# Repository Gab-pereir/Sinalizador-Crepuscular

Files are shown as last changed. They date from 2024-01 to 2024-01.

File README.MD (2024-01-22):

# Sinalizador Crepuscular Automatizado

Seja bem vindo a esse repositório dedicado ao desenvolvimento de um Sinalizador Crepuscular Automatizado. Este projeto tem como objetivo confeccionar uma placa de circuito impresso para um sistema inovador de iluminação em transições entre dia e noite

## Descrição

O sinalizador Crepuscular utiliza tecnologia avançada para detectar mudanças na luz ambiente, proporcionando iluminação eficiente e personalizada durante as diferentes fases do dia

## Clonar o Repositório e Abrir no KiCad

Se você deseja explorar ou contribuir para o projeto do Sinalizador Crepuscular, siga os passos abaixo para clonar o repositório e abrir o projeto no KiCad:

### 1. Faça um Fork do Repositório

- No canto superior direito desta página, clique no botão "Fork" para criar uma cópia do repositório no seu próprio perfil.

### 2. Clone o Repositório

- Abra o terminal no seu sistema.

- Utilize o seguinte comando para clonar o repositório para o seu ambiente local 

  ```bash
  git clone https://github.com/Gab-pereir/Sinalizador-Crepuscular.git

### 3. Abra o Projeto no KiCad

- Abra o KiCad.

- Vá para "File" > "Open Project".

- Navegue até o diretório do projeto clonado.

- Escolha o arquivo de projeto correspondente à placa desejada 

## Organização das Pastas

```Sinalizador-Crepuscular/
|-- fonte/
|   |-- docs/
|   |   |-- Especificações elétricas da Placa da Fonte
|   |
|   |-- gerbers/
|   |   |-- Arquivos Gerber relacionados à Placa da Fonte
|   |
|   |-- OutrosDocumentos/
|       |-- Outros documentos relevantes para a Placa da Fonte
|
|-- haste_superior/
|   |-- docs/
|   |   |-- Especificações elétricas da Haste Superior
|   |
|   |-- gerbers/
|   |   |-- Arquivos Gerber relacionados à Haste Superior
|   |
|   |-- OutrosDocumentos/
|       |-- Outros documentos relevantes para a Haste Superior
|
|-- logica_de_comando/
|   |-- docs/
|   |   |-- Especificações elétricas da Lógica de Comando
|   |
|   |-- gerbers/
|   |   |-- Arquivos Gerber relacionados à Lógica de Comando
|   |
|   |-- OutrosDocumentos/
        |-- Outros documentos relevantes para a Lógica de Comando

```

## Contribuindo

Sinta-se à vontade para contribuir para o desenvolvimento do Sinalizador Crepuscular Automatizado.

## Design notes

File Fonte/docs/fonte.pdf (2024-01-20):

A energização do circuito deve ser feita através do conector CN4 (CN4-1 e CN4-2), no qual devem ser conectados os fios do secundário de um transformador externo (T1). O tranformador deve ter o primário com possibilidade de alimentação em 110V ou 220V, e secundário de 12V com corrente de aproximadamente 200mA (2,4W).

Se o enrolamento primário do transformador for de 220V com derivação central (0-110V-220V), uma chave HH de 3 polos deve ser utilizada para permitir a seleção da tensão de alimentação do transformador de acordo com a tensão da rede elétrica do local de instalação. As cargas (lâmpadas) também devem ter a tensão de operação compatível com a rede.

Observe que existem dois fios que derivam dos polos da rede, e que seguem para o conector CN1 (CN1-1 e CN1-2), responsável pela energização das cargas (lâmpadas de sinalização). O fusível F2 tem a função de proteger o circuito de alimentação e deve ser montado num porta fusível. As cargas possuem proteção independente.

Fonte

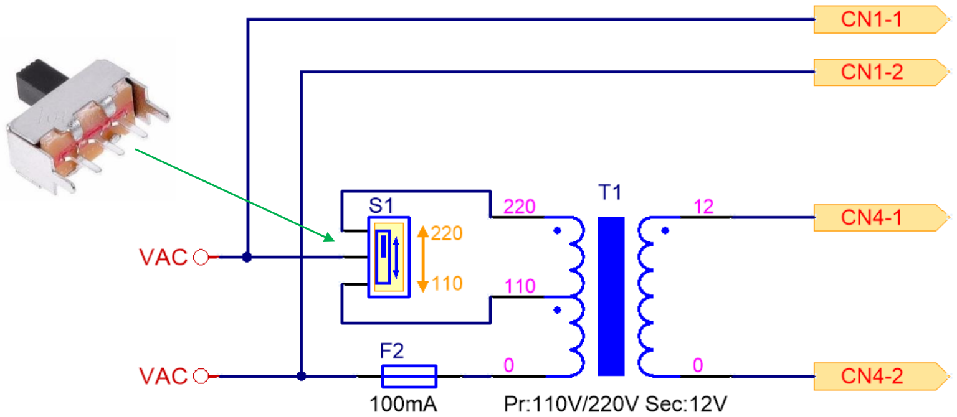
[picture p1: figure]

Para os transformadores que possuem dois enrolamentos primários (0V-110V), uma chave HH de 6 polos deve ser utilizada conforme mostra o esquema abaixo. Nesse esquema, a chave faz o fechamento em série (220V) ou em paralelo (110V) dos enrolamentos do transformador levando em conta os polos magnéticos. A figura sugere também o esquema de ligação caso o secundário tenha dois enrolamentos de 12V (2 x 12V).

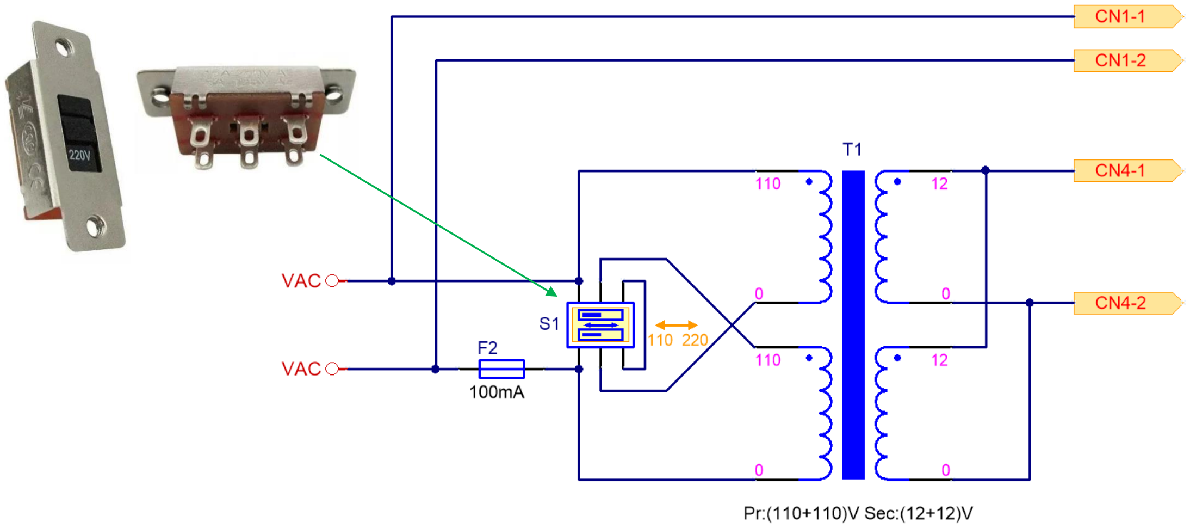
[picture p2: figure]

A tensão de 12VAC do secundário do transformador ligado no conector CN4, é aplicada numa ponte retificadora formada pelos diodos D3, D4, D5 e D6. O sinal retificado é então filtrado pelo capacitor C3 dando origem ao barramento VCC com tensão DC não regulada. A tensão nesse barramento varia de acordo com a tensão da rede na faixa de (14,5V a 19,5 V).

O led LD3 tem a função de sinalizar quando o circuito está energizado. R8 é o resistor de limitação de corrente desse led.

A regulação da fonte é feita através do diodo zener D7 (9,1V@500mW) e pelos resistores de limitação de corrente R9 e R10. O capacitor C4 em paralelo com o diodo zener, é chamado de “capacitor tanque” e tem a função de diminuir a impedância da fonte de 9,0V.O uso de dois resistores em paralelo de 560Ω/250mW ao invés de um único resistor de 270Ω/500mW, permite que resistores de 250mW sejam utilizados.

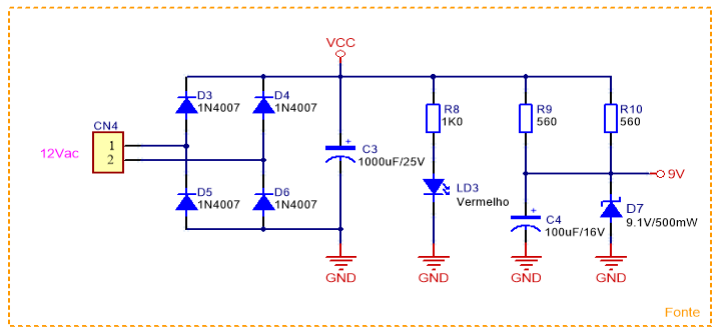
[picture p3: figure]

A determinação do resistor de limitação da corrente do diodo zener foi feita com base na estimativa do consumo de corrente do circuito que é de aproximadamente 15mA.

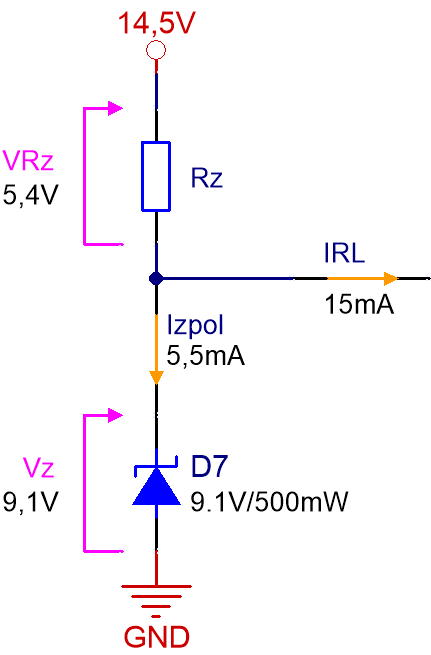
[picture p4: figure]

- Valor de Rz
Para a determinação do valor ôhmico do resistor Rz, devemos utilizar o valor mínimo da tensão VCC não regulada (14,5V). Nessa condição a corrente do diodo zener deve ser aquela que coloca o componente dentro da faixa nominal de operação. Essa corrente é conhecida como corrente mínima de polarização do diodo zener (Izpol). Na prática esse valor é de aproximadamente 10% da corrente máxima do diodo.

Rz =

Vcc − Vz

IRZ

=

Vcc − Vz

Izpol + IRL

=

Vcc − Vz

0,1 ∙

Pz
Vz + IRL

=

(14,5V − 9,1)V

0,1 ∙

500mW
9,1V + 15mA

= 263,5Ω

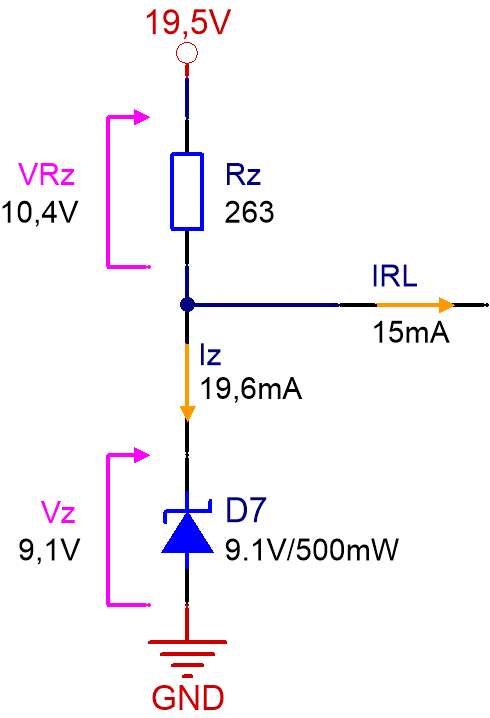
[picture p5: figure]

PRZ =

VRZ

2
RZ

=

(Vcc − Vz)

2
RZ

=

(19,5 − 9,1)

2V
263,5Ω

= 410,5mW

- Potência de Rz
A potência máxima que o resistor Rz terá que dissipar, deve ser determinada na condição de tensão de rede alta. Nessa condição, a tensão VCC não regulada deve ser aproximadamente 19,5V.

Rz = 263Ω/410mW

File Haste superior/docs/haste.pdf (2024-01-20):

Sensor de luminosidade

No circuito do sinalizador, o jumper J1 tem a função de selecionar um dos modos de operação: Sempre ligado ou Sensor de luminosidade ativo.

- Sempre ligado
Nesse modo de operação o sensor de luminosidade não atua, ou seja, a sinalização é feita independentemente da luminosidade do ambiente. Para operar nesse modo, o jumper JP1 precisa estar fechado.
- Sensor ativo
Nesse modo de operação a sinalização é dependente da luminosidade do ambiente, e a sinalização só será ativada quando a luminosidade cair abaixo de um valor preestabelecido, ajustado através do potenciômetro P2. Para operar nesse modo, o jumper JP1 precisa estar aberto.

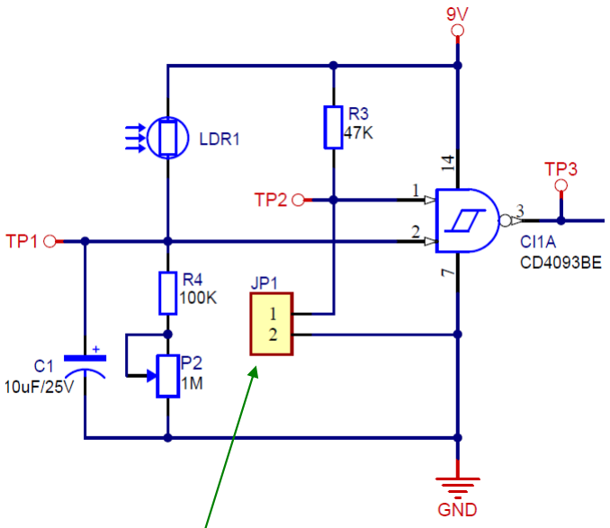
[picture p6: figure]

Configuração do modo
de operação

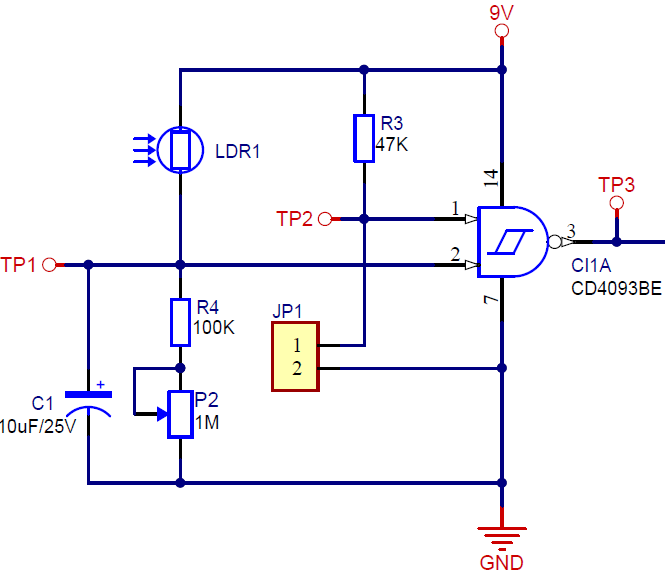
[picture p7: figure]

O desenho ao lado corresponde ao sensor de luminosidade do circuito e como mencionado anteriormente, o jumper JP1 define o modo de operação do sinalizador.

Com JP1 fechado (modo “sempre ligado”), o pino 1 do circuito integrado 4093 (entrada da porta lógica NAND) é colocado em 0V (NL0) obrigando a saída da porta (pino3 do 4093) ir para NL1, independentemente do nível lógico presente na outra entrada (pino 2 do 4093), que é fornecido pelo sensor de luminosidade. A saída da porta lógica permanecerá em NL1, enquanto JP1 estiver fechado, independentemente da luminosidade do ambiente.

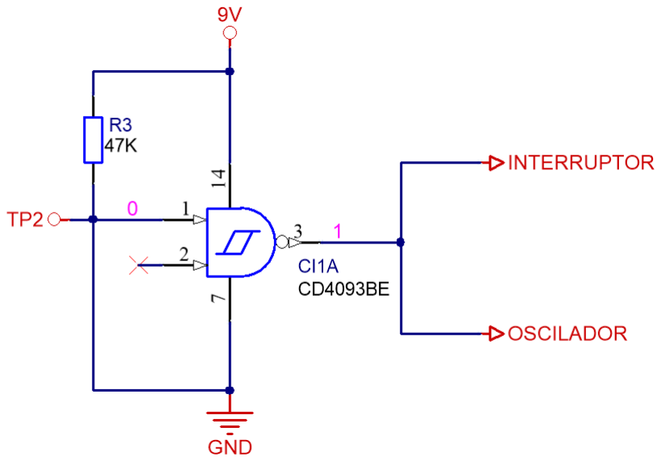
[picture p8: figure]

O sinal de saída da porta lógica NAND (pino 1 do 4093) excita dois circuitos posteriores chamados: Interruptor e Oscilador.

No circuito Interruptor, o sinal do pino 1 do 4093, é utilizado para ativar (NL1) ou desativar (NL0) um relé (K1) que opera como interruptor do sinal da rede aplicada no conector CN1.

No circuito Oscilador, o sinal do pino 1 do 4093, é utilizado para ativar (NL1) ou desativar (NL0) o módulo oscilador, responsável pela intermitência das lâmpadas.

Com JP1 aberto (modo “sensor ativo”), o pino 1 do circuito integrado 4093 (TP2) assume NL1 devido ao resistor de pull-up que referencia a entrada da porta com a fonte de 9V. Com TP2 em NL1, a saída da porta lógica se torna dependente do estado lógico interpretado pelo pino 2 do 4093. Nesse caso, a saída da porta lógica irá para NL1, quando a tensão no ponto TP1, cair abaixo da tensão VL do schmitt trigger, e irá para NL0, quando a tensão no ponto TP1, crescer acima da tensão VH do schmitt trigger.

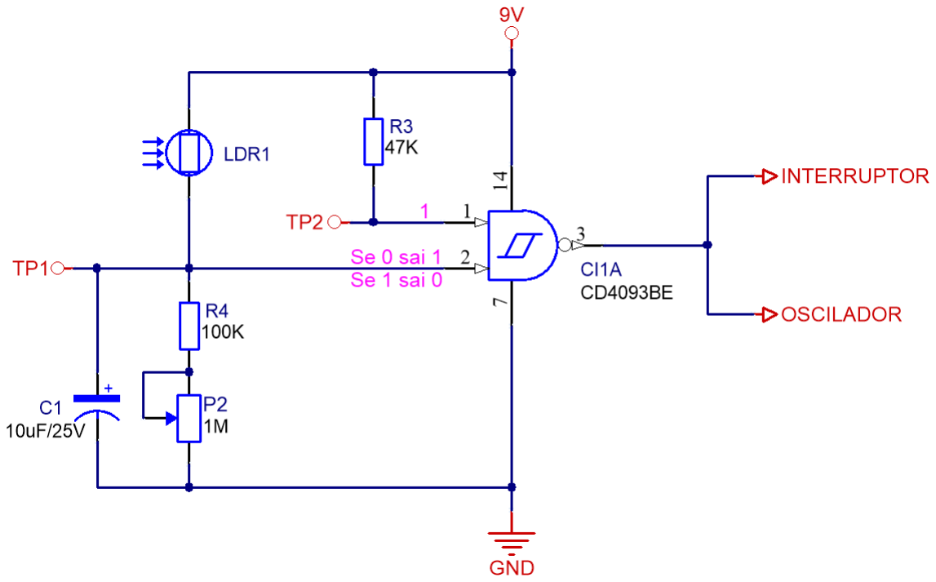
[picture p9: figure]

Para 9V de alimentação, VL = 3,7V e VH = 5,6V.

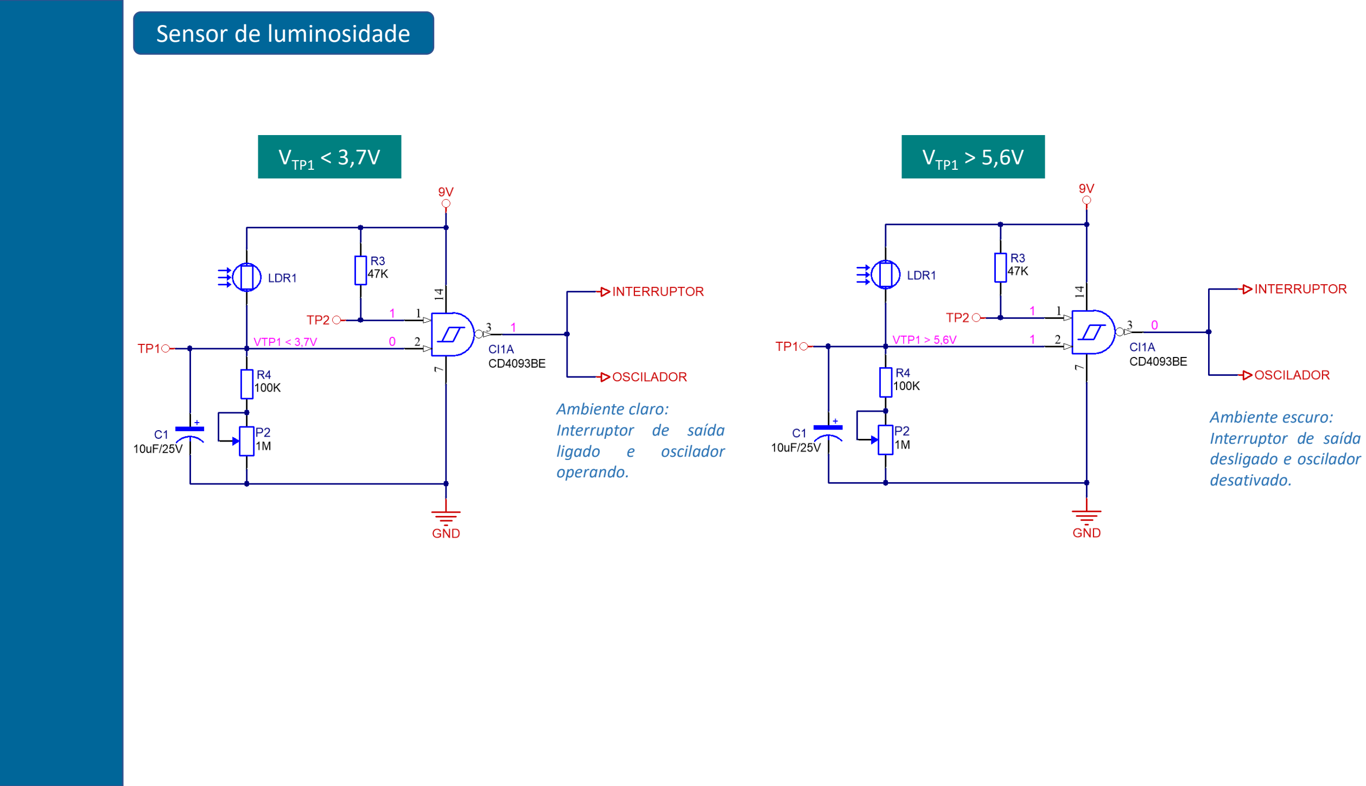
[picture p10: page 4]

VTP1 < 3,7V | VTP1 > 5,6V

Ambiente claro:
Interruptor de saída
ligado | e | oscilador
operando.

Ambiente escuro:
Interruptor de saída
desligado e oscilador
desativado.

Do que foi exposto, podemos concluir que nesse modo de operação, a ativação do módulo oscilador e o fechamento do interruptor de saída, é dependente da tensão presente no ponto TP1, ou seja, a tensão sobre o capacitor C1.

Observando o circuito, notamos que o LDR (Resistor Dependente de Luz) forma um divisor de tensão com R4 + P2, e como a resistência do LDR varia em função da luminosidade do ambiente, concluímos que a tensão no ponto TP1 também varia em função dela. De acordo com o gráfico Resistencia x Luminosidade do LDR mostrado abaixo, a resistência do LDR aumenta quando a luminosidade do ambiente diminui (escurece) e vice-versa.

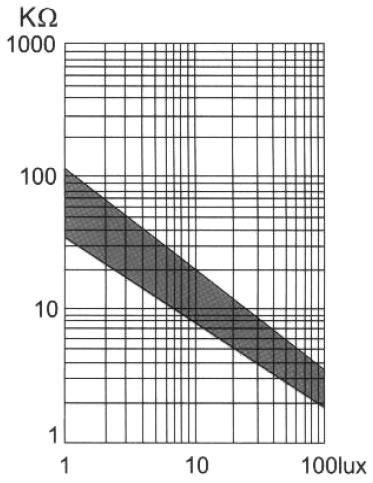
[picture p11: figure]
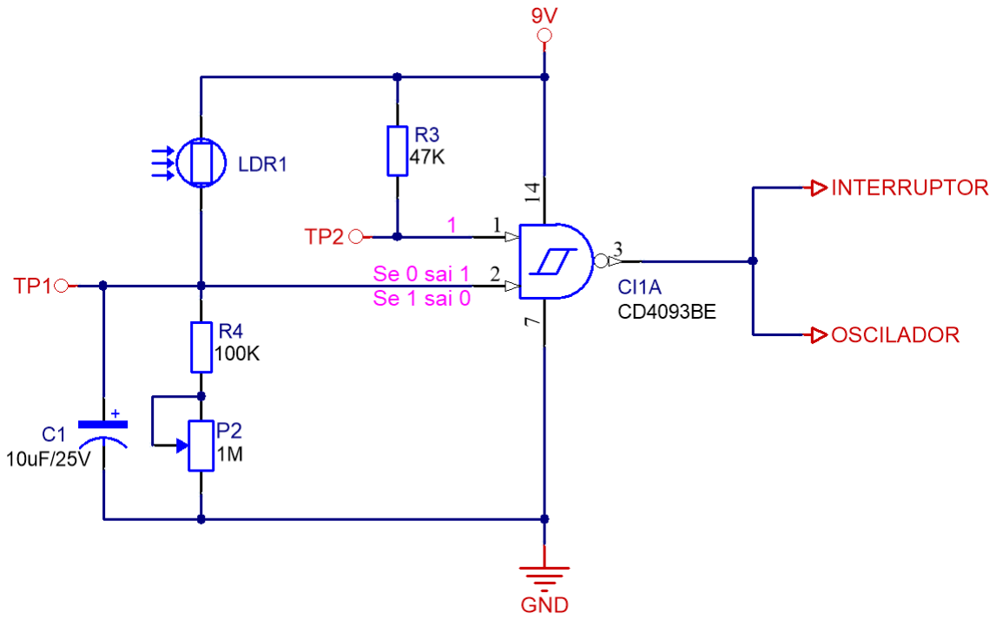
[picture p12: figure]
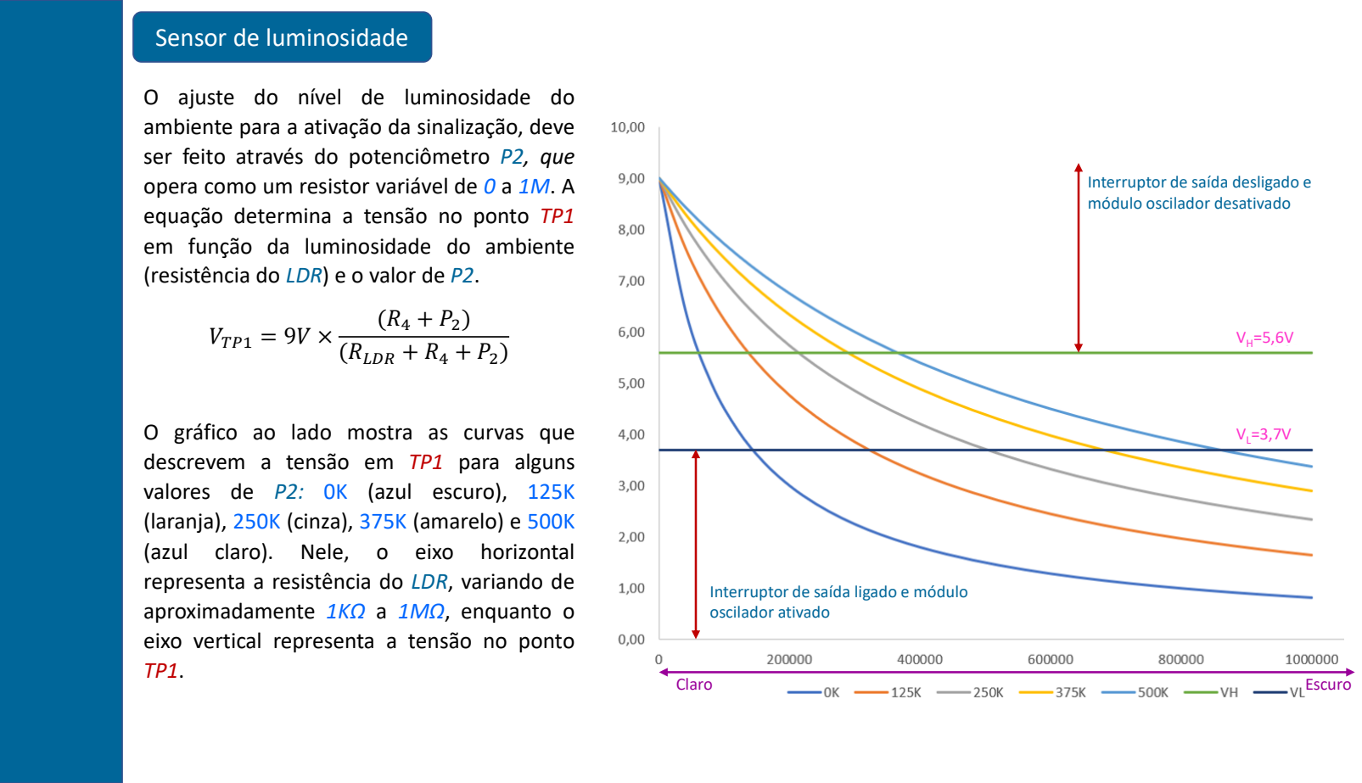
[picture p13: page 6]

O ajuste do nível de luminosidade do ambiente para a ativação da sinalização, deve ser feito através do potenciômetro P2, que opera como um resistor variável de 0 a 1M. A equação determina a tensão no ponto TP1 em função da luminosidade do ambiente (resistência do LDR) e o valor de P2.

VTP1 = 9V ×

(R4 + P2)
(RLDR + R4 + P2)

O gráfico ao lado mostra as curvas que descrevem a tensão em TP1 para alguns valores de P2: 0K (azul escuro), 125K (laranja), 250K (cinza), 375K (amarelo) e 500K (azul claro). Nele, o eixo horizontal representa a resistência do LDR, variando de aproximadamente 1KΩ a 1MΩ, enquanto o eixo vertical representa a tensão no ponto TP1.

VH=5,6V

VL=3,7V

Interruptor de saída ligado e módulo oscilador ativado

Interruptor de saída desligado e módulo oscilador desativado

Claro | Escuro

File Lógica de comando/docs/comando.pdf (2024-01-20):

Módulo Oscilador

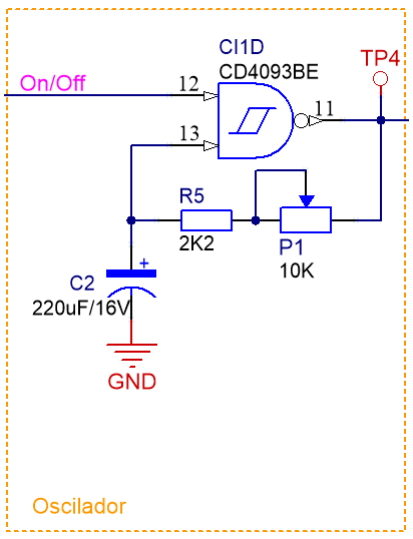
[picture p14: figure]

O circuito oscilador utiliza uma segunda porta lógica do circuito integrado 4093, e possui uma entrada de controle (On/Off) que ativa ou desativa a oscilação do sinal de saída.

Quando On/Off é colocada em NL0, o oscilador é desativado, pois a saída (TP4 = pino 11 do 4093) vai para NL1 e permanece nesse estado.

Quando On/Off é colocada em NL1, o circuito oscilador é ativado, e o sinal retangular gerado aparece na saída (TP4 = pino 11 do 4093).

Devemos observar que quem controla a entrada On/Off do modulo oscilador é a saída do sensor de luminosidade.

- JP1 fechado
Sensor de luminosidade = 1 → Oscilador = ativo e TP4 = Oscilando
- JP1 aberto

Claro Sensor de luminosidade = 0 → Oscilador = inativo e TP4 = 1

Escuro Sensor de luminosidade = 1 → Oscilador = ativo e TP4 = Oscilando

Circuito Oscilador

Quando o oscilador é ativado, um sinal retangular periódico de amplitude igual a 9V, é gerado no pino 11 do 4093 (TP4). Os tempos Ton e Toff desse sinal, podem ser determinados pelas equações abaixo:

TON = (R5 + P1) ∙ C2 ∙ ln

9V − VL
9V − VH

TON = (2K2 + P1) ∙ 220. 10⁻⁶
- ln

9 − 3,7
9 − 5,6

TONmin = 2K2 + 0 ∙ 220. 10⁻⁶
- ln

9 − 3,7
9 − 5,6

= 214,9ms

TONmax = 2K2 + 10K ∙ 220. 10⁻⁶
- ln

9 − 3,7
9 − 5,6

= 1,19s

TOFF = (R5 + P1) ∙ C2 ∙ ln

VH
VL

TOFF = (2K2 + P1) ∙ 220. 10⁻⁶
- ln

5,6
3,7

TOFFmin = 2K2 + 0 ∙ 220. 10⁻⁶
- ln

5,6
3,7

= 200,6ms

TOFFmax = 2K2 + 10K ∙ 220. 10⁻⁶
- ln

5,6
3,7

= 1,11s

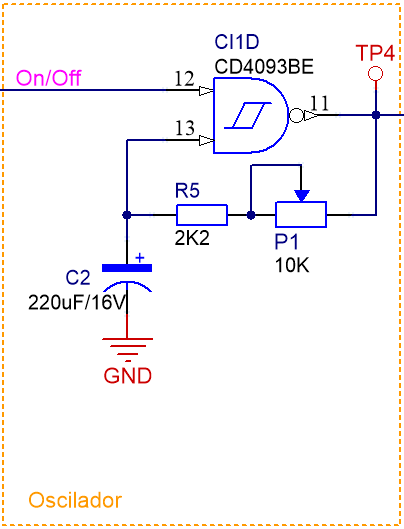
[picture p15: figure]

- Para P1 = 0Ω

T = TON + TOFF = 214,9ms + 200,6ms = 415,5ms

Freq =

1
T

=

1
415,5ms

= 2,4Hz

Dcy % =

TON
T

=

214,9ms
415,5ms
- 100 = 51,7%

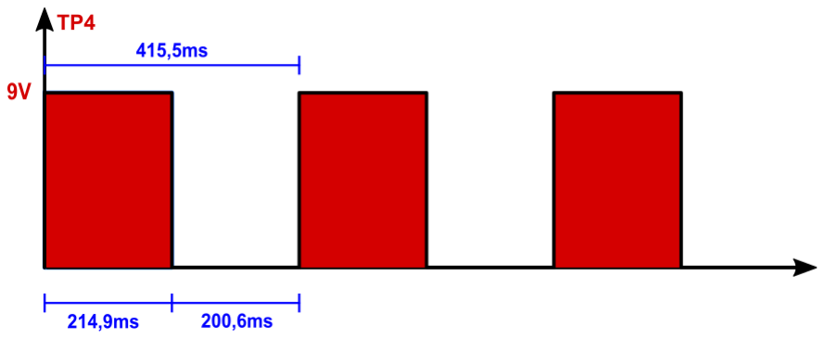
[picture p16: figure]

- Para P1 = 10KΩ

T = TON + TOFF = 1,19s + 1,11s = 2,3s

Freq =

1
T

=

1
2,3s = 434,8mHz

Dcy % =

TON
T

=

1,19s
2,3s ∙ 100 = 51,7%

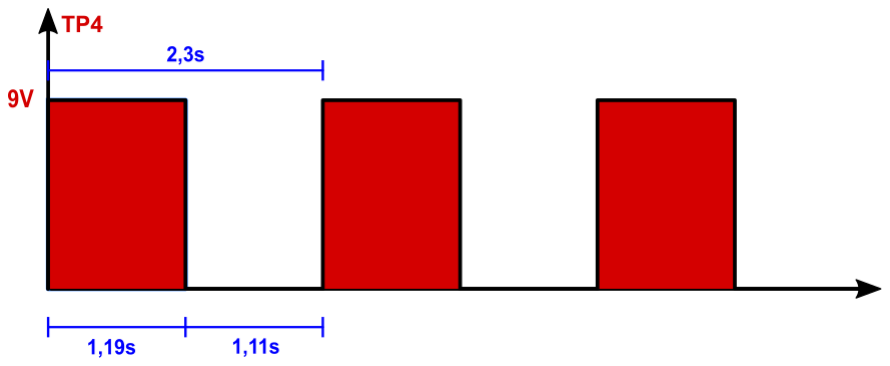
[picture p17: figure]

Inversor de alta impedância

O inversor de alta impedância possui duas funções: a primeira é inverter o estado lógico da saída do circuito oscilador, impedindo que o relé de distribuição fique energizado quando ele estiver desativado, ou seja, sem oscilação. A segunda é impedir que a malha de excitação da base do transistor Q2, interfira na frequência do sinal de saída do oscilador, devido a diminuição da tensão de saída da porta lógica.

IbQ2 =

9V − Vbe
R7

=

9 − 0,7
10K

= 830μA

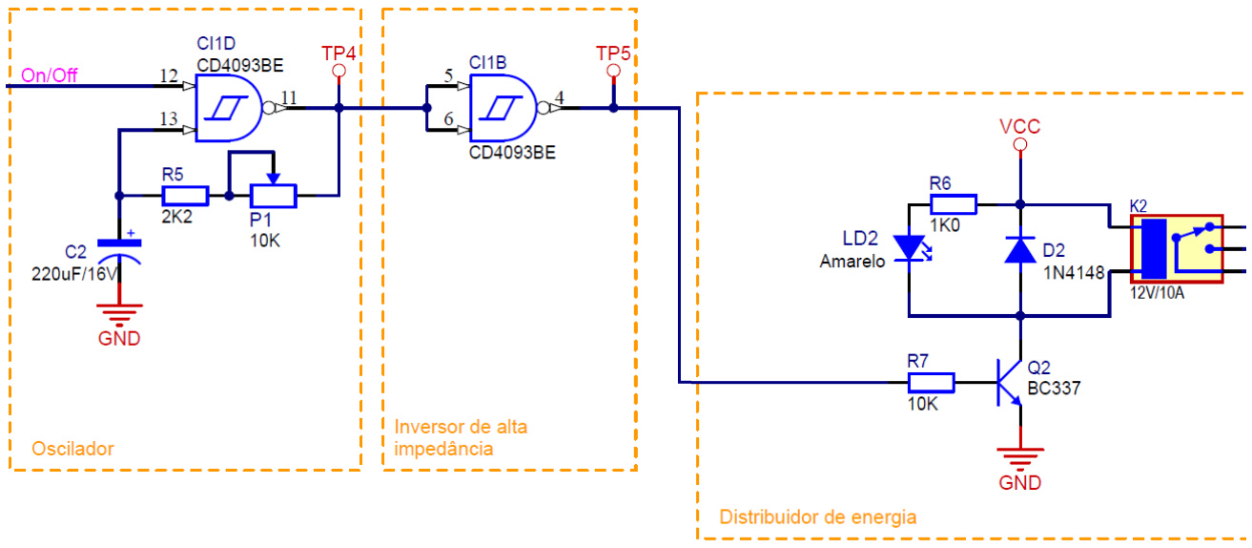
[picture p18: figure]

Circuito Interruptor

O circuito interruptor de saída tem a função de energizar ou desenergizar o módulo de distribuição de energia. O módulo utiliza o relé K1 (1 contato reversor) para aplicar uma das fases da rede no polo comum do relé de distribuição. O acionamento do relé interruptor é feito através do transistor Q1 (NPN), controlado pelo sinal de saída do sensor de luminosidade (TP3 = On/Off).

O módulo possui um led (LD1) que acende para indicar que o transistor está ligado, que a bobina do relé está energizada, e que a fase da rede está aplicada no polo central do relé de distribuição.

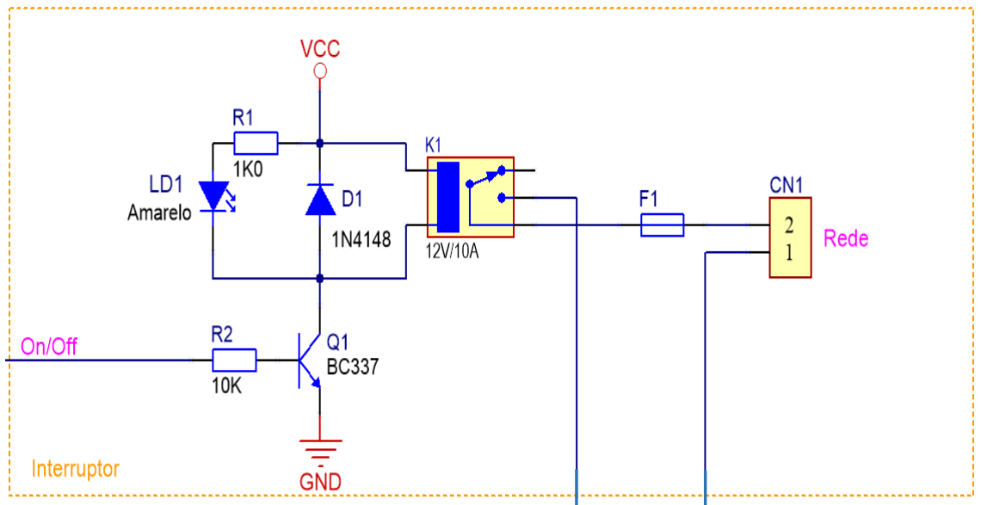
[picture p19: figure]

Para o polo 1 dos conectores das lâmpadas

Para o polo central do relé de distribuição.

Circuito Interruptor

O diodo D1 (freewheeling) tem a função de proteger o transistor no momento da desenergização da bobina do relé.

O sinal da rede deve ser aplicado no conector CN1. O fusível F1 tem a função de proteger a saída contra sobrecargas ou curto-circuitos nos conectores das lâmpadas (CN2 e CN3).

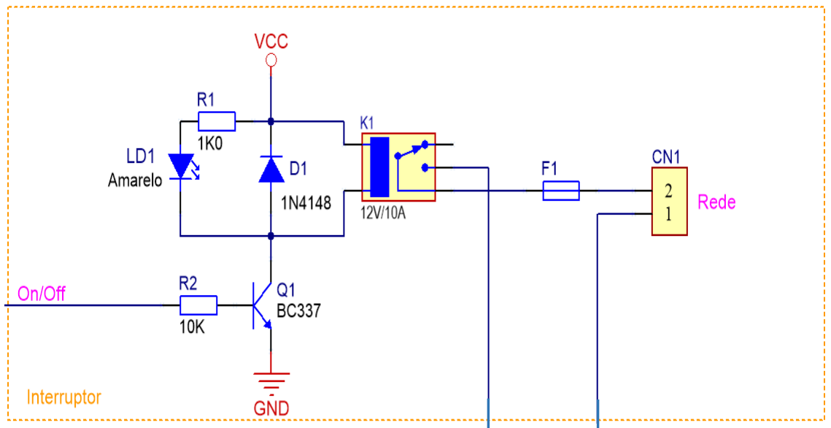
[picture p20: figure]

Para o polo 1 dos conectores das lâmpadas

Para o polo central do relé de distribuição.

Módulo distribuidor de energia

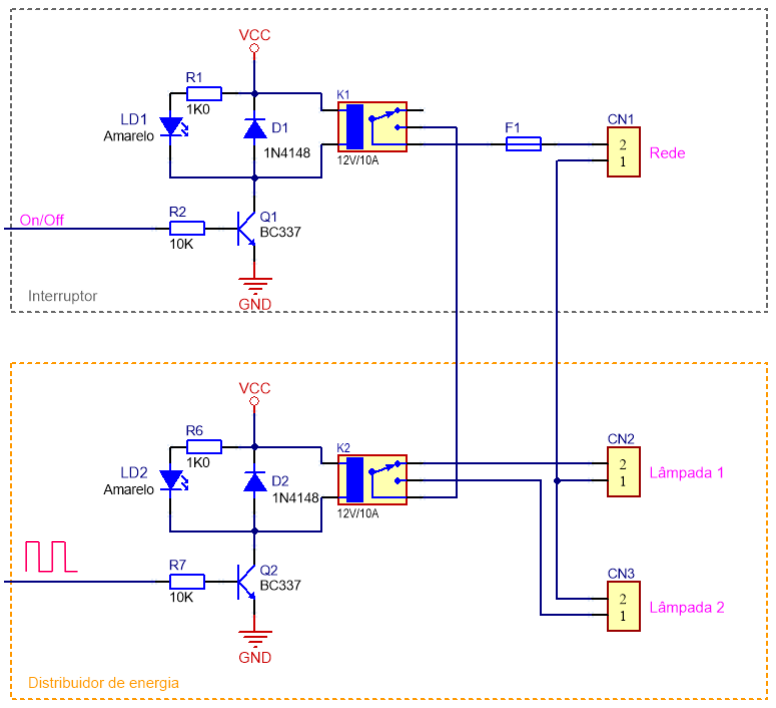
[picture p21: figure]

O módulo de distribuição de energia utiliza o relé K2 (1 contato reversor) para fazer a energização ora do conector CN3, ora do conector CN4, obedecendo os tempos Ton e Toff do sinal de saída do módulo oscilador.

Quando em Ton o relé K2 energiza o conector CN2, e quando em Toff, o conector CN3.

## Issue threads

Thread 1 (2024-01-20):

📁 Criação da estrutura inicial do projeto

Gab-pereir, 2024-01-20:
# Descrição
Criação da estrutura básica do projeto Sinalizador Crepuscular.

# Tarefas

- [ ] Criação da pastas "lógica de comando"
- [ ] Criação da pastas "fonte"
- [ ] Criação da pasta "haste superior"
- [ ] Adicionar os arquivos iniciais em cada uma das pastas
- [ ] Verificar se a estrutura está corretamente organizada

Closed 2024-01-20.

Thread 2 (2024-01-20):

💡 Implementação da lógica de comando para o Sinalizador Crepuscular

Gab-pereir, 2024-01-20:
# Descrição

Nessa etapa, será desenvolvido a lógica de controle para o sinalizador Crepuscular.

# Tarefas:

- [x] Criar o esquemático do circuito do sinalizador crepuscular.
- [x] Adicionar componentes ao esquemático
- [x] Realizar a conexão dos componentes no esquemático, garantindo que todas as conexões sejam corretas.
- [x] Verificar se não há erros ou conflitos no esquemático, como conexões faltantes ou componentes incorretamente conectados.
- [x] Gerar a lista de materiais (BOM - Bill of Materials) a partir do esquemático, identificando todos os componentes e suas quantidades necessárias.
- [x] Criar a placa de circuito impresso (PCB - Printed Circuit Board) a partir do esquemático e das regras de design.
- [x] Posicionar os componentes na PCB, levando em consideração o layout e a disposição física dos elementos.
- [x] Realizar o roteamento das trilhas na PCB, garantindo que todas as conexões sejam feitas corretamente e seguindo as regras de design.
- [x] Verificar se não há erros de roteamento, como trilhas cruzadas ou curtos-circuitos.
- [x] Gerar os arquivos de fabricação da PCB, incluindo os arquivos Gerber, para enviar para a fabricação da placa.

Closed 2024-01-20.

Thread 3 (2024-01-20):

🔌 Desenvolvimento do circuito impresso da fonte de alimentação

Gab-pereir, 2024-01-20:
# Descrição

Nessa etapa, será desenvolvido a placa de circuito impresso da fonte de alimentação

# Tarefas:

- [x] Criar o esquemático do circuito
- [x] Adicionar componentes ao esquemático
- [x] Realizar a conexão dos componentes no esquemático, garantindo que todas as conexões sejam corretas.
- [x] Verificar se não há erros ou conflitos no esquemático, como conexões faltantes ou componentes incorretamente conectados.
- [x] Gerar a lista de materiais (BOM - Bill of Materials) a partir do esquemático, identificando todos os componentes e suas quantidades necessárias.
- [x] Criar a placa de circuito impresso (PCB - Printed Circuit Board) a partir do esquemático e das regras de design.
- [x] Posicionar os componentes na PCB, levando em consideração o layout e a disposição física dos elementos.
- [x] Realizar o roteamento das trilhas na PCB, garantindo que todas as conexões sejam feitas corretamente e seguindo as regras de design.
- [x] Verificar se não há erros de roteamento, como trilhas cruzadas ou curtos-circuitos.
- [x] Gerar os arquivos de fabricação da PCB, incluindo os arquivos Gerber, para enviar para a fabricação da placa.

Closed 2024-01-20.

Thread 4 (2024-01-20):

💡 Criação do circuito impresso da haste de leds

Gab-pereir, 2024-01-20:
# Descrição

Nessa etapa, será desenvolvido a placa de circuito impresso da haste de led

# Tarefas:

- [x] Criar o esquemático do circuito
- [x] Adicionar componentes ao esquemático
- [x] Realizar a conexão dos componentes no esquemático, garantindo que todas as conexões sejam corretas.
- [x] Verificar se não há erros ou conflitos no esquemático, como conexões faltantes ou componentes incorretamente conectados.
- [x] Gerar a lista de materiais (BOM - Bill of Materials) a partir do esquemático, identificando todos os componentes e suas quantidades necessárias.
- [x] Criar a placa de circuito impresso (PCB - Printed Circuit Board) a partir do esquemático e das regras de design.
- [x] Posicionar os componentes na PCB, levando em consideração o layout e a disposição física dos elementos.
- [x] Realizar o roteamento das trilhas na PCB, garantindo que todas as conexões sejam feitas corretamente e seguindo as regras de design.
- [x] Verificar se não há erros de roteamento, como trilhas cruzadas ou curtos-circuitos.
- [x] Gerar os arquivos de fabricação da PCB, incluindo os arquivos Gerber, para enviar para a fabricação da placa.

Closed 2024-01-21.

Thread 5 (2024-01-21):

📝 Atualização da documentação e conclusão da primeira versão do projeto

Gab-pereir, 2024-01-21:
# Descrição

Esta Issue concentra-se na melhoria da documentação e conclusão da primeira versão da  do projeto, abordando revisões, instruções claras de configuração e garantindo consistência. O objetivo é marcar a conclusão após assegurar que todas as informações críticas estejam atualizadas.

# Tarefas

- [x] Revisar a documentação existente para identificar áreas que precisam ser atualizadas.
- [x] Incluir instruções claras sobre como configurar e executar o projeto.
- [x] Revisar a formatação e a consistência em toda a documentação.
- [x] Marcar a conclusão da primeira versão da documentação na Issue correspondente.
- [x] Certificar-se de que todas as informações críticas estão atualizadas para refletir a versão mais recente do projeto.

Closed 2024-01-22.

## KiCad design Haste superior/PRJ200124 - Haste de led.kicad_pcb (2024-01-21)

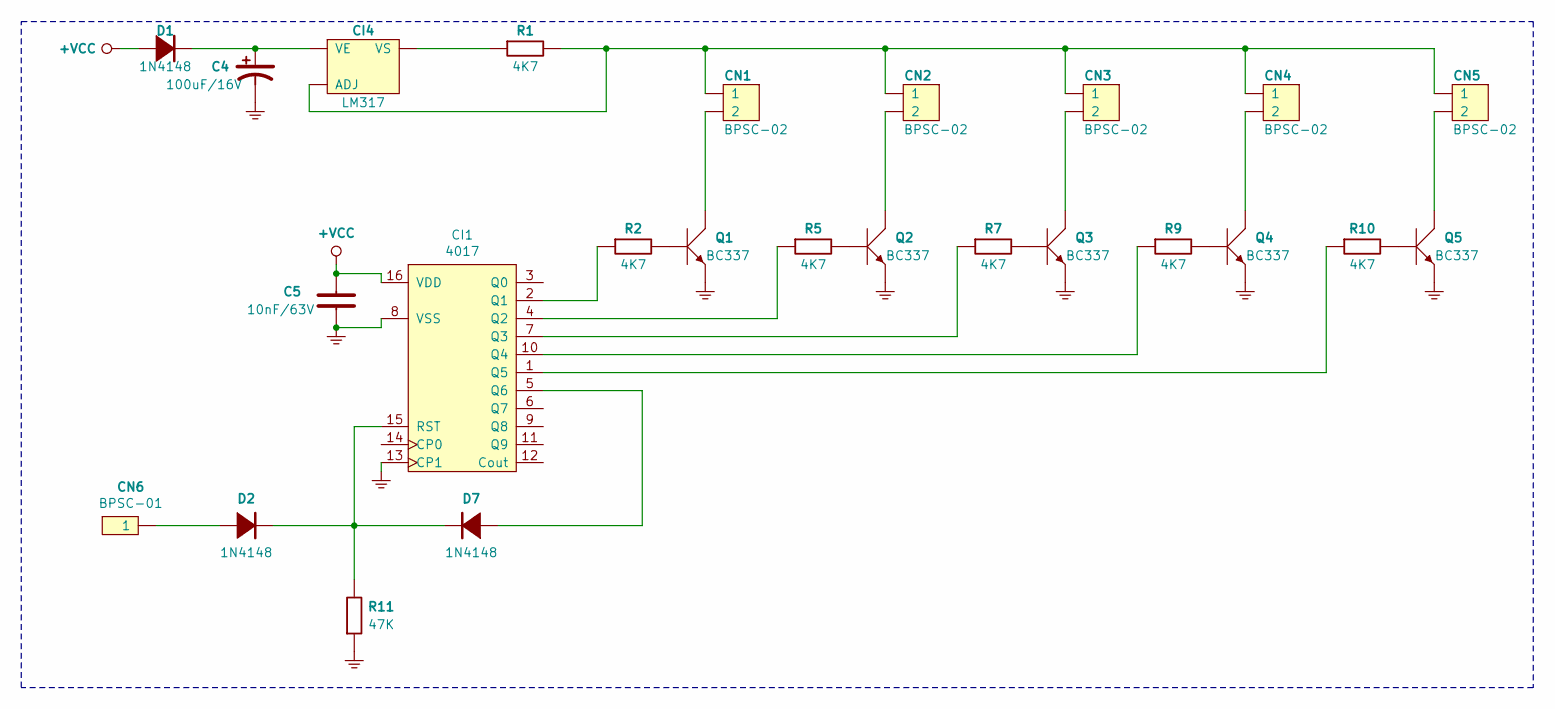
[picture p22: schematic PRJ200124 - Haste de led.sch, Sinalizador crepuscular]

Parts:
C4: 100uF(16V)-Panasonic(FCA); Capacitor(Eletrolitico)-Radial(6.3x11.0)mm-(Azul_Marinho); Part Number Part Number
C5: 10nF(63V)-TDK(B32529)-(10%); Capacitor(MKT)-TDK(B32529)-(7.3x2.5x6.5)mm; Part Number B32529C0103K
CI1: CD4017BE; PDIP016N; Part Number CD4017BE
CI4: LM317BTG(180); TO220-3(180); Part Number LM317BTG
CN1, CN2, CN3, CN4, CN5: BPSC-02(Metaltex-BP); BPSC-02; Part Number BPSC-02
CN6: BPSC-01(Metaltex-BP); BPSC-01; Part Number BPSC-01
D1, D2, D7: 1N4148; DO-35(Vidro-Vermelho); Part Number Part Number
Q1, Q2, Q3, Q4, Q5: BC337; TO92-3(Bent-Lead); Part Number BC337
R1, R2, R5, R7, R9, R10, R11: CFR12-(5%); CFR12-(5p); Part Number Part Number

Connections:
+VCC: C5.2, CI1.16 (VDD), D1.2 (A)
GND: C4.2, C5.1, CI1.8 (VSS), CI1.13 (CP1), Q1.3 (E), Q2.3 (E), Q3.3 (E), Q4.3 (E), Q5.3 (E), R11.1 (A)
unnamed: C4.1, CI4.3 (VE), D1.1 (K)
unnamed: CI4.1 (ADJ), CN1.1, CN2.1, CN3.1, CN4.1, CN5.1, R1.2 (B)
unnamed: CI4.2 (VS), R1.1 (A)
unnamed: CI1.1 (Q5), R10.1 (A)
unnamed: CI1.2 (Q1), R2.1 (A)
unnamed: CI1.4 (Q2), R5.1 (A)
unnamed: CI1.5 (Q6), D7.2 (A)
unnamed: CI1.7 (Q3), R7.1 (A)
unnamed: CI1.10 (Q4), R9.1 (A)
unnamed: CI1.15 (RST), D2.1 (K), D7.1 (K), R11.2 (B)
unnamed: CN1.2, Q1.1 (C)
unnamed: CN2.2, Q2.1 (C)
unnamed: CN3.2, Q3.1 (C)
unnamed: CN4.2, Q4.1 (C)
unnamed: CN5.2, Q5.1 (C)
unnamed: CN6.1, D2.2 (A)
unnamed: Q1.2 (B), R2.2 (B)
unnamed: Q2.2 (B), R5.2 (B)
unnamed: Q3.2 (B), R7.2 (B)
unnamed: Q4.2 (B), R9.2 (B)
unnamed: Q5.2 (B), R10.2 (B)

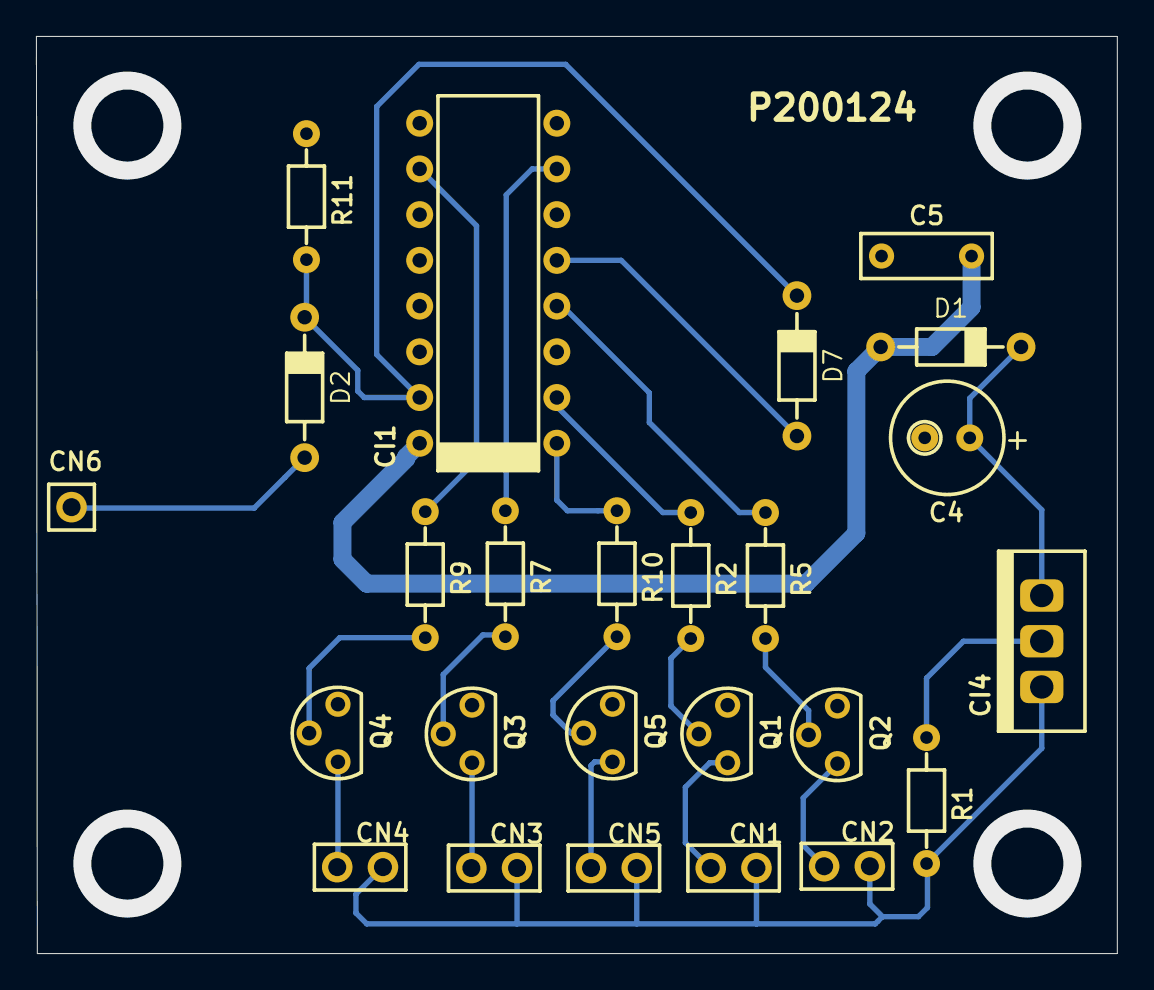
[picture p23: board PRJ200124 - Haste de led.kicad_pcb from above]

Board: 2 copper layers, 60.0 x 51.0 mm, 25 parts (0 on the bottom side), 23 nets.

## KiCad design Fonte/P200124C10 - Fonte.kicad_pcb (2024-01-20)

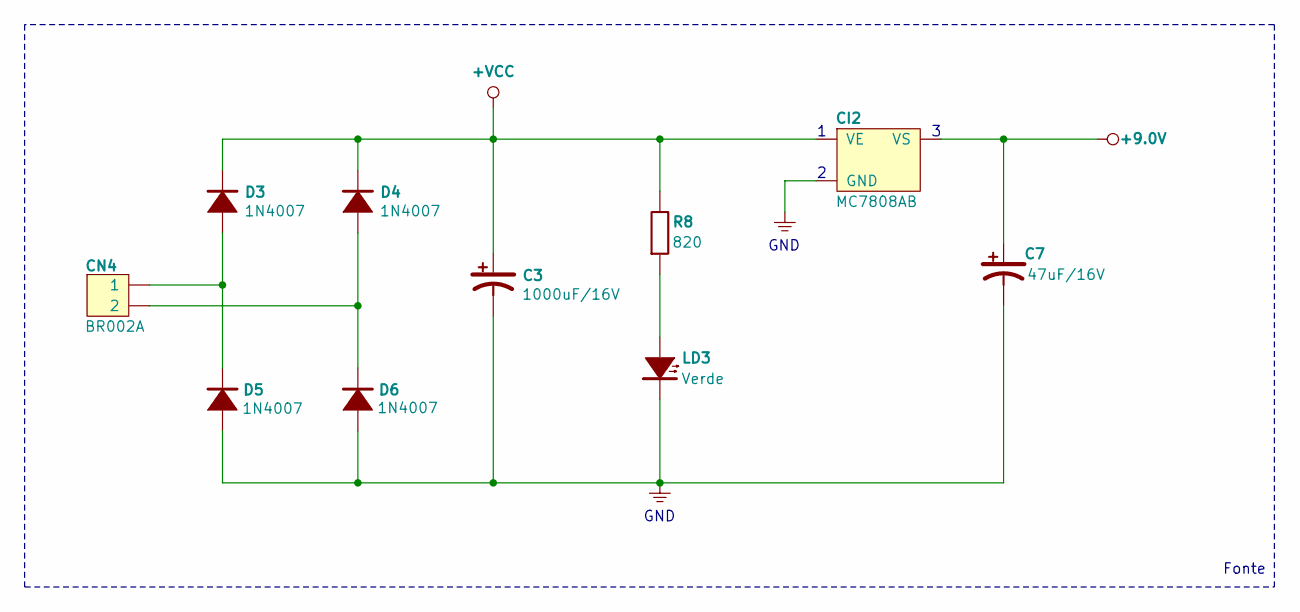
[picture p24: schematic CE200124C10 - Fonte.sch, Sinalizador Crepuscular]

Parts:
C3: 1000uF(16V)-Panasonic(FCA); Capacitor(Eletrolitico)-Radial(10.0x25.0)mm-(Azul_Marinho); Part Number Part Number
C7: 47uF(16V)-Panasonic(FCA); Capacitor(Eletrolitico)-Radial(5.0x11.0)mm-(Azul_Marinho); Part Number Part Number
CI2: MC7808B-(180); TO220-3(180); Part Number MC7808BTG
CN4: BR002A(Metaltex-BR0); BR002A-(Metaltex-BR0); Part Number BR002A
D3, D4, D5, D6: 1N4007; DO-41(Plastico); Part Number Part Number
LD3: Led-Redondo(3.0mm)-Pth-Verde(Difuso); Led(Pth)-Redondo(3.0mm)-Verde(Difuso); Part Number *
R8: CFR12-(5%); CFR12-(5p); Part Number Part Number

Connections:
+9.0V: C7.1, CI2.3 (VS)
+VCC: C3.1, CI2.1 (VE), D3.1 (K), D4.1 (K), R8.2 (B)
GND: C3.2, C7.2, CI2.2 (GND), D5.2 (A), D6.2 (A), LD3.1 (K)
unnamed: CN4.1, D3.2 (A), D5.1 (K)
unnamed: CN4.2, D4.2 (A), D6.1 (K)
unnamed: LD3.2 (A), R8.1 (A)

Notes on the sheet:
Fonte
GND

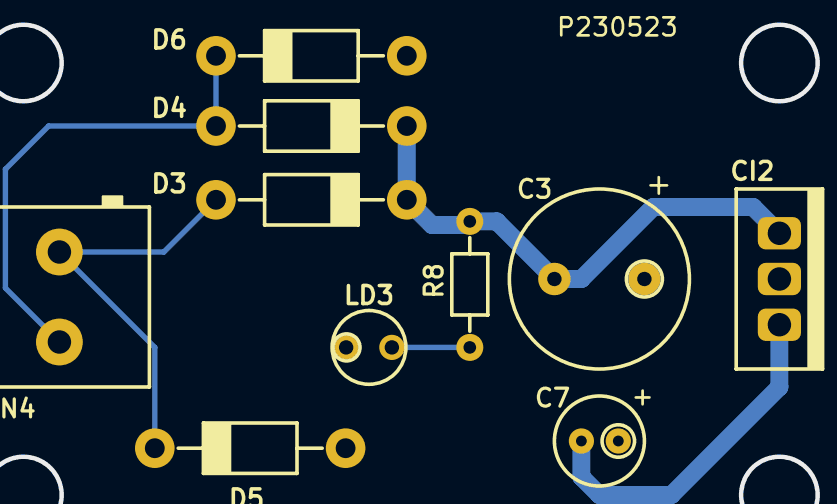
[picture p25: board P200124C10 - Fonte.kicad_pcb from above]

Board: 2 copper layers, 10 parts (0 on the bottom side), 6 nets.

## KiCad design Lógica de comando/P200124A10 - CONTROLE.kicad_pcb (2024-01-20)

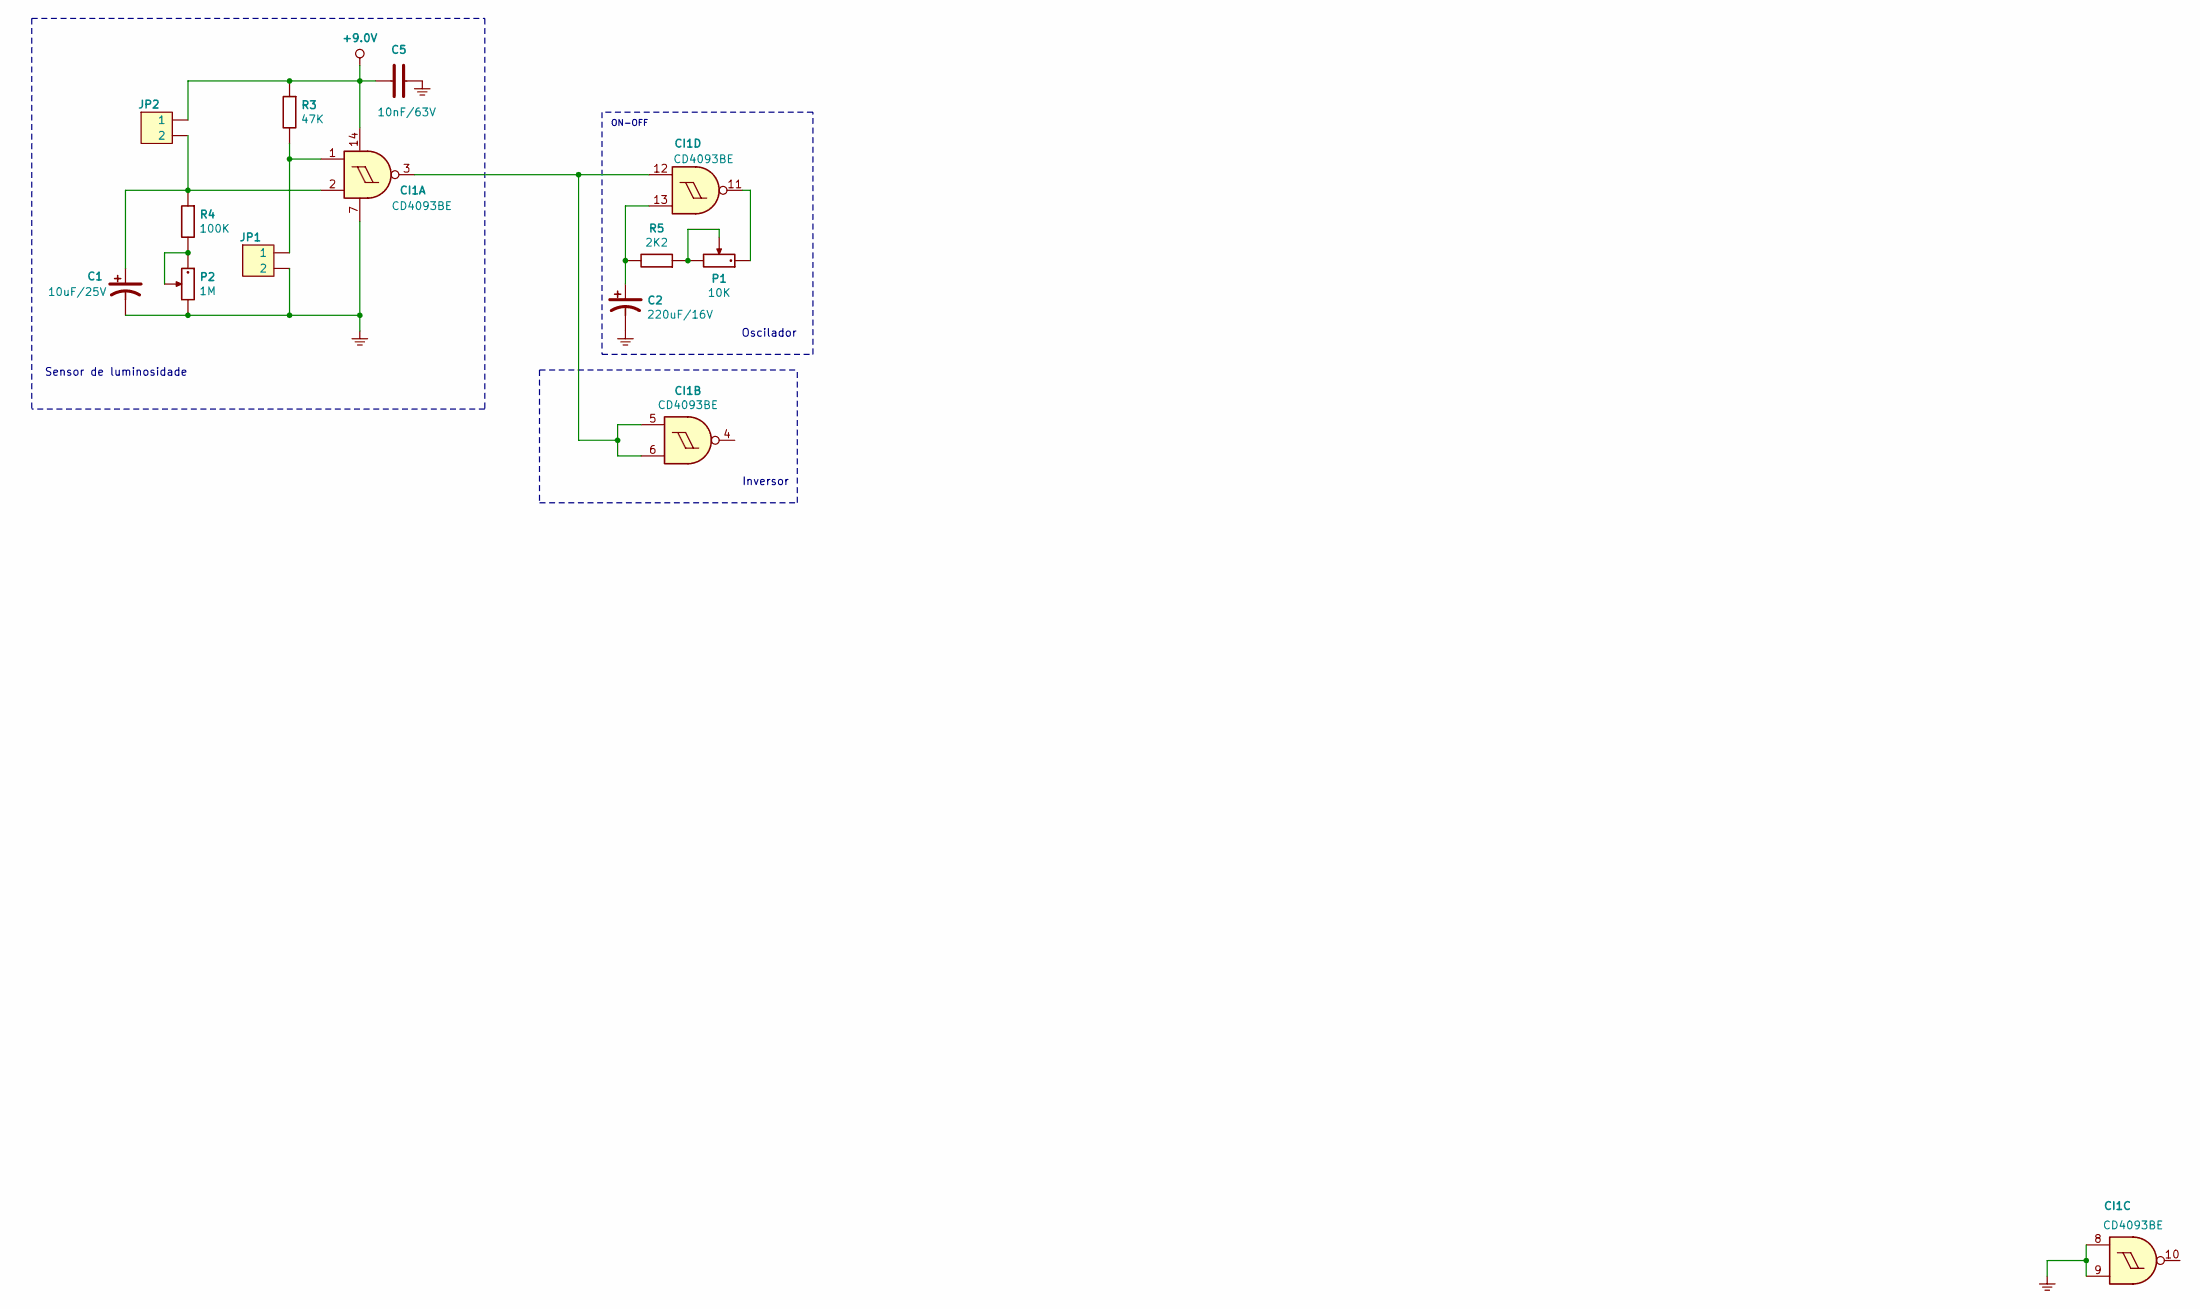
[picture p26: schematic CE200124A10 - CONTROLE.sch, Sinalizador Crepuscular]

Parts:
C1: 10uF(25V)-Panasonic(FCA); Capacitor(Eletrolitico)-Radial(4.0x7.0)mm-(Azul_Marinho); Part Number EEAFC1E100
C2: 220uF(16V)-Panasonic(FCA); Capacitor(Eletrolitico)-Radial(8.0x11.5)mm-(Azul_Marinho); Part Number Part Number
C5: 10nF(63V)-TDK(B32529)-(10%); Capacitor(MKT)-TDK(B32529)-(7.3x2.5x6.5)mm; Part Number B32529C0103K
CI1: CD4093BE; PDIP014N; Part Number CD4093BE
JP1, JP2: BPSC-02(Metaltex-BP); BPSC-02; Part Number BPSC-02
P1: 10K-Bourns(3386-F); TRIMPOT-Bourns(3386-F); Part Number 3386F-1-103
P2: 1M-Bourns(3386-F); TRIMPOT-Bourns(3386-F); Part Number 3386F-1-105
R3, R4, R5: CFR12-(5%); CFR12-(5p); Part Number Part Number

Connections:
+9.0V: C5.1, CI1.14 (VDD), JP2.1, R3.1 (A)
GND: C1.2, C2.2, C5.2, CI1.7 (VSS), CI1.8 (A3), CI1.9 (B3), JP1.2, P2.3
unnamed: C1.1, CI1.2 (B1), JP2.2, R4.1 (A)
unnamed: C2.1, CI1.13 (B4), R5.2 (B)
unnamed: CI1.1 (A1), JP1.1, R3.2 (B)
unnamed: CI1.11 (S4), P1.1
unnamed: CI1.3 (S1), CI1.5 (A2), CI1.6 (B2), CI1.12 (A4)
unnamed: P1.2, P1.3, R5.1 (A)
unnamed: P2.1, P2.2, R4.2 (B)

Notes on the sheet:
Sensor de luminosidade
Inversor
ON-OFF
Oscilador

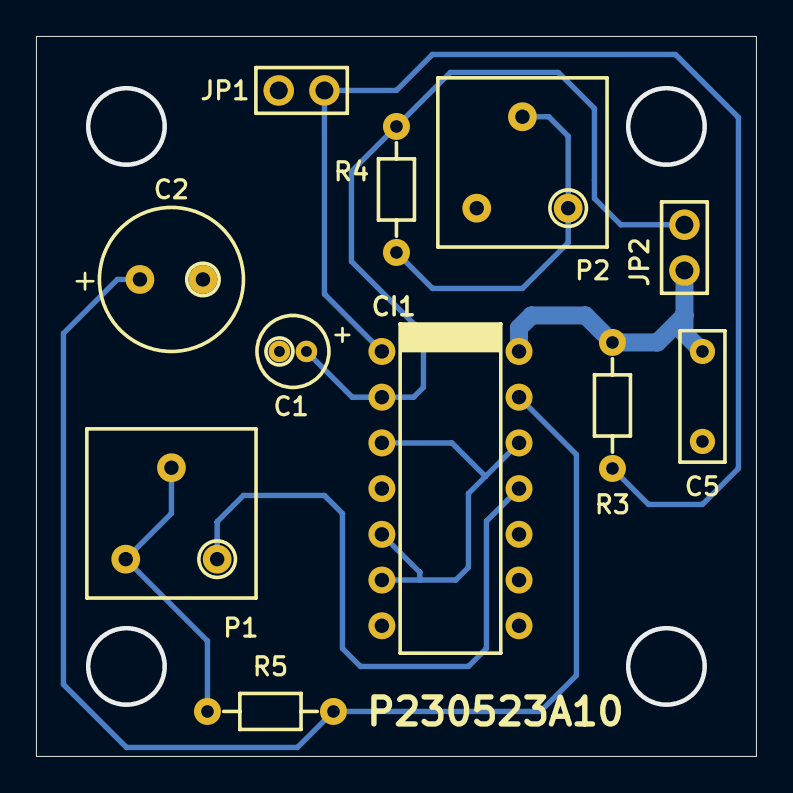
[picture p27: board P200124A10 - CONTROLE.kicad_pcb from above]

Board: 2 copper layers, 40.0 x 40.0 mm, 11 parts (0 on the bottom side), 9 nets.

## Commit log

2024-01-20 📁 Adicionando a estrutura básica do projeto - Closes #1
2024-01-20 ✨ Implementação da lógica de comando - fixes #2
    [CE200124A10 - CONTROLE.sch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]
2024-01-20 ✨ Implementação do circuito impresso da fonte de alimentação - Fixes #3
    [CE200124C10 - Fonte.sch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]
2024-01-21 💡 Criação do circuito impresso da haste de leds - Closes #4
    [PRJ200124 - Haste de led.kicad_pcb, PRJ200124 - Haste de led.sch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]
2024-01-22 📄 Atualização da documentação do projeto e inclusão do arquivo README - Closes #5
